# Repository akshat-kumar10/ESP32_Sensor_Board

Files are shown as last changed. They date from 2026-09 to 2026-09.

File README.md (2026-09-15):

# ESP32-C3-02 IoT Sensor Board

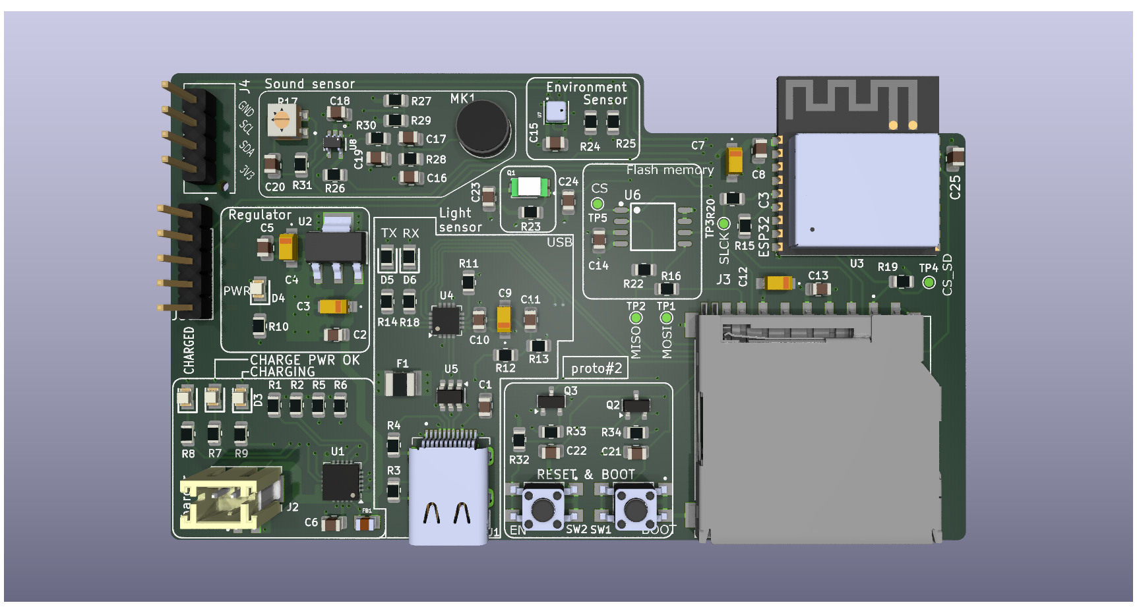
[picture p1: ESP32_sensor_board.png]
PCB Layout


## Overview
This repository contains the KiCad 9.0 design files for a custom IoT sensor board powered by the ESP32-C3-02 SoC[cite: 1]. It features integrated Li-ion battery management and diverse environmental sensors for edge data logging and prototyping[cite: 1].

## Key Features
* **Power Management:** Integrated TP4056 IC for safe single-cell Li-ion charging with thermal regulation, under-voltage lockout, and trickle charging[cite: 1].
* **Dual Power Inputs:** USB-C for charging/data and a dedicated LiPo battery connector[cite: 1].
* **Modular Architecture:** Expandable via additional I2C devices with optimized PCB traces for minimal power loss[cite: 1].

## Primary Components
* **Microcontroller:** ESP32-C3-02 SoC (Wi-Fi and BLE connectivity)[cite: 1].
* **Sensors:** BME280 (temperature, humidity, pressure), ambient light, and sound sensors[cite: 1].
* **Peripherals:** Mini SD card reader, additional flash memory, and I2C OLED display[cite: 1].
* **Charge Indicators:** Dedicated LEDs for charging and full charge status[cite: 1].

## Repository Structure
* `/ESP32 Project Gerbers` - Manufacturing and fabrication files.
* `/Libraries` & `/Project_Library.pretty` - Project-specific symbols and footprints.
* `/Datasheets` - Component documentation[cite: 1].
* `ESP32 sensor board.kicad_pro` - KiCad 9.0 project file.
* `ESP32 sensor board.kicad_pcb` - Physical PCB layout.
* `*.kicad_sch` - Hierarchical schematic design files (Sensors, User Interface, ESP32).

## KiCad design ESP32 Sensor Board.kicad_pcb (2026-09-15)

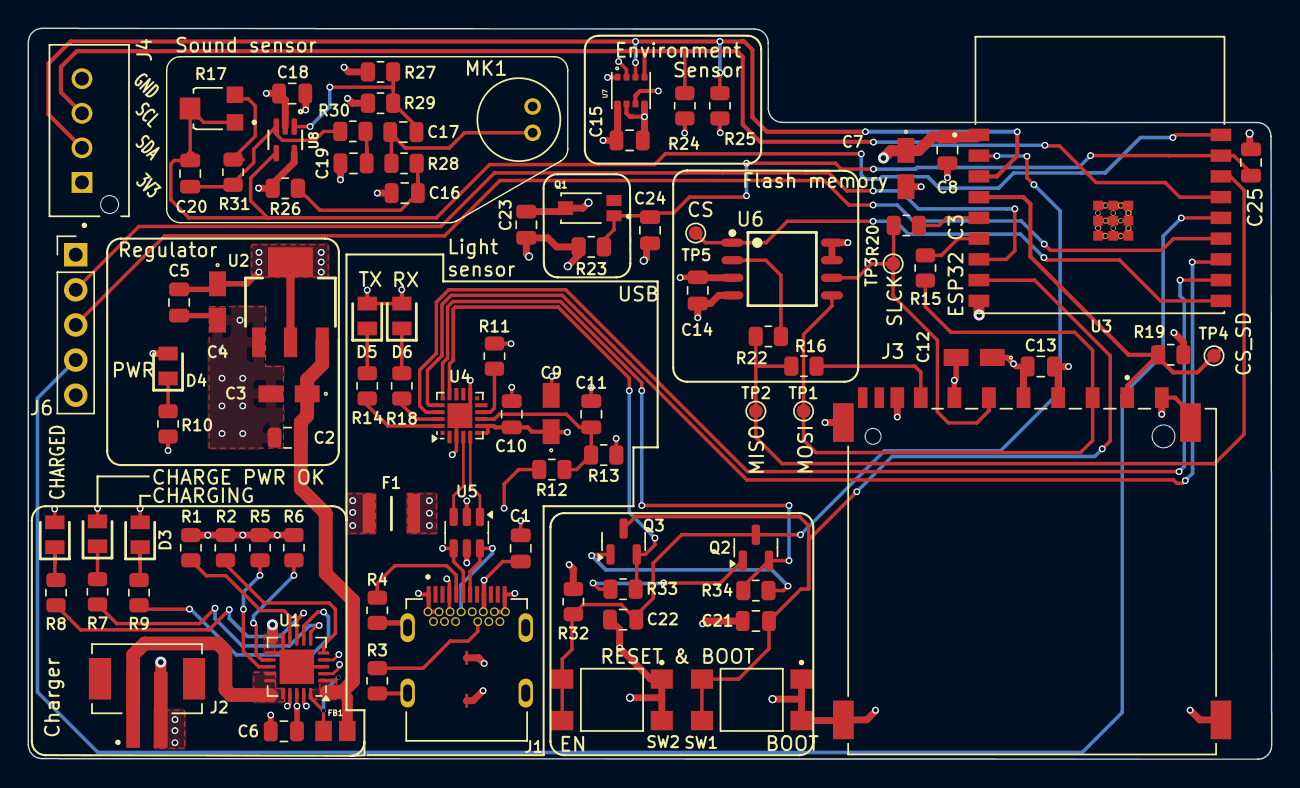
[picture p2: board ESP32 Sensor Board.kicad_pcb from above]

Board: 4 copper layers, 89.9 x 52.8 mm, 90 parts (0 on the bottom side), 60 nets.

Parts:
C1, C2, C5, C8, C10, C13, C14, C15, C16, C18, C21, C23: 0.1u; C_0805_2012Metric
C3, C4, C7, C12: 10u; T491A
C6, C11, C22: 1u; C_0805_2012Metric
C9: 4.7u; T491A
C17, C24, C25: 10n; C_0805_2012Metric
C19: 10u; C_0805_2012Metric
C20: 100p; C_0805_2012Metric
D1, D4, D6: Red; LEDC2012X120N
D2, D5: Green; LEDC2012X120N
D3: Blue; LEDC2012X120N
F1: 0ZCH0110AF2E; FUSC3226X100N
FB1: FBMJ2125HM330-T; BEADC2012X105N
J1: USB_C_Receptacle; BELFUSE_SS-52400-002
J2: JST_2mm_LiPo; JST_B2B-PH-SM4-TB
J3: GSD090012SEU; AMPHENOL_GSD090012SEU
J4: B4B-XH-AM; JST_B4B-XH-AM__LF__SN_
J6: Conn_01x05; PinHeader_1x05_P2.54mm_Vertical
MK1: CMC-5042PF-AC; CUI_CMC-5042PF-AC
Q1: TEMT6000X01; TRANS_TEMT6000X01
Q2, Q3: BC817; SOT-23
R1, R2, R19, R23, R32, R33, R34: 10K; R_0805_2012Metric
R3, R4: 5k1; R_0805_2012Metric
R5, R26, R28: 2K; R_0805_2012Metric
R6: 20K; R_0805_2012Metric
R7, R8, R9: 470; R_0805_2012Metric
R10, R14, R18: 330; R_0805_2012Metric
R11, R30: 1K; R_0805_2012Metric
R12: 22K1; R_0805_2012Metric
R13: 47K5; R_0805_2012Metric
R15, R16, R20, R22: 50; R_0805_2012Metric
R17: 35WR100KLFTR; TRIM_35WR100KLFTR
R24, R25: 4K7; R_0805_2012Metric
R27, R29: 1M; R_0805_2012Metric
R31: 22K; R_0805_2012Metric
SW1, SW2: 1101NE; SW_TL3305AF260QG
TP1: Test MOSI; TestPoint_Pad_D1.0mm
TP2: Test MISO; TestPoint_Pad_D1.0mm
TP3: Test CLK; TestPoint_Pad_D1.0mm
TP4: TEST CS_SD; TestPoint_Pad_D1.0mm
TP5: TEST CS; TestPoint_Pad_D1.0mm
U1: MCP73871; QFN-20-1EP_4x4mm_P0.5mm_EP2.5x2.5mm
U2: LM1117MPX-3.3_NOPB; VREG_LM1117MPX-3.3
U3: ESP32-C3-WROOM-02-H4; MODULE_ESP32-C3-WROOM-02-H4
U4: CP2102N-A02-GQFN20; SiliconLabs_QFN-20-1EP_3x3mm_P0.5mm_EP1.8x1.8mm
U5: USBLC6-2SC6; SOT-23-6
U6: W25Q32JVSSIQ; SOIC127P790X216-8N
U7: BME280; PSON65P250X250X100-8N
U8: MAX4466EXK+T; SOT65P210X110-5N

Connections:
3.3V: C4.1 (+), C5.1, C7.1 (+), C8.1, C9.1 (+), C10.1, C12.1 (+), C13.2, C14.1, C15.2, C18.1, C23.1, D4.2 (A), D5.2 (A), D6.2 (A), J3.4 (VDD1), J4.1, J6.1, Q1.3, R11.1, R19.2, R24.1, R25.1, R26.2, R27.2, R32.2, U2.2 (VOUT_2), U2.4 (VOUT_4), U3.1 (3V3), U4.6 (VDD), U4.7 (VREGIN), U6.3 (~WP(IO2)), U6.7 (~HOLD/~RESET(IO3)), U6.8 (VCC), U7.2 (CSB), U7.6 (VDDIO), U7.8 (VDD), U8.5 (VCC)
+5V: C2.1, C3.1 (+), FB1.1, U2.3 (VIN)
/+5V_USB: C6.1, D1.2 (A), D2.2 (A), D3.2 (A), F1.2, U1.2 (VPCC), U1.4 (PROG2), U1.17 (CE), U1.18 (IN), U1.19 (IN)
/CHARGED: R8.1, U1.8 (STAT1/~LBO)
/CHARGING: R9.1, U1.7 (STAT2)
/CHARGING_POWER_GOOD: R7.1, U1.6 (~PG)
/ESP32-C3-02/BOOT: C21.1, Q3.3 (C), SW1.2, SW1.4, U3.8 (IO9)
/ESP32-C3-02/CS: TP5.1, U3.10 (IO10), U6.1 (~CS)
/ESP32-C3-02/CS_SD: J3.1 (CD/DAT3), R19.1, TP4.1, U3.4 (IO5)
/ESP32-C3-02/DTS: Q3.2 (E), R33.1, U4.15 (~CTS)
/ESP32-C3-02/EN: C22.1, Q2.3 (C), R32.1, SW2.2, SW2.4, U3.2 (EN)
/ESP32-C3-02/GPIO8: J6.2, U3.7 (IO8)
/ESP32-C3-02/GPIO18: J6.3, U3.13 (IO18)
/ESP32-C3-02/GPIO19: J6.4, U3.14 (IO19)
/ESP32-C3-02/MIC_OUT: C20.2, R17.1, R17.2, U3.18 (IO0), U8.4 (OUT)
/ESP32-C3-02/MISO_DO: R16.2, R22.1, TP2.1, U3.16 (IO2)
/ESP32-C3-02/MOSI_DI: J3.2 (CMD), R15.1, TP1.1, U6.5 (DI(IO0))
/ESP32-C3-02/PHOTO_C: C24.1, C25.1, Q1.1, R23.1, U3.17 (IO1)
/ESP32-C3-02/RTS: Q2.2 (E), R34.1, U4.16 (~RTS)
/ESP32-C3-02/RX_TX: U3.12 (TXD), U4.17 (RXD)
/ESP32-C3-02/SCL: J4.3, R24.2, U3.15 (IO3), U7.4 (SCK)
/ESP32-C3-02/SCLK: J3.5 (CLK), R20.1, TP3.1, U6.6 (CLK)
/ESP32-C3-02/SDA: J4.2, R25.2, U3.3 (IO4), U7.3 (SDI)
/ESP32-C3-02/TX_RX: U3.11 (RXD), U4.18 (TXD)
/ESP32-C3-02/USB_D+: U4.4 (D+), U5.3 (I/O2)
/ESP32-C3-02/USB_D-: U4.5 (D-), U5.1 (I/O1)
/PWR_LED: D4.1 (K), R10.2
/USB_DN: J1.A7 (DN1), J1.B7 (DN2), U5.6 (I/O1)
/USB_DP: J1.A6 (DP1), J1.B6 (DP2), U5.4 (I/O2)
/VBAT: J2.1, U1.14 (V_{BAT}), U1.15 (V_{BAT}), U1.16 (V_{BAT_SENSE})
/VBUS: C1.1, F1.1, J1.A4 (VBUSA1), J1.A9 (VBUSA2), J1.B4 (VBUSB1), J1.B9 (VBUSB2), R12.1, U5.5 (VBUS)
GND: C1.2, C2.2, C3.2 (-), C4.2 (-), C5.2, C6.2, C7.2 (-), C8.2, C9.2 (-), C10.2, C11.2, C12.2 (-), C13.1, C14.2, C15.1, C16.2, C18.2, C19.1, C21.2, C22.2, C23.2, C24.2, C25.2, J1.A1 (GNDA1), J1.A12 (GNDA2), J1.B1 (GNDB1), J1.B12 (GNDB2), J1.G1 (GND/SHIELD), J1.G2 (GND/SHIELD), J1.G3 (GND/SHIELD), J1.G4 (GND/SHIELD), J1.S1 (GND/SHIELD), J1.S2 (GND/SHIELD), J1.S3 (GND/SHIELD), J1.S4 (GND/SHIELD), J2.2, J3.3 (VSS1), J3.6 (VSS2), J3.8 (DAT1), J3.9 (DAT2), J3.G1 (SHIELD_GND), J3.G2 (SHIELD_GND), J3.G3 (SHIELD_GND), J3.G4 (SHIELD_GND), J4.4, J6.5, MK1.GND, R1.2, R2.2, R3.2, R4.2, R5.2, R6.2, R10.1, R13.2, R23.2, R29.1, SW1.1, SW1.3, SW2.1, SW2.3, U1.3 (SEL), U1.10 (V_{SS}), U1.11 (V_{SS}), U1.21 (V_{SS}), U2.1 (GND), U3.9 (GND), U3.19 (GND), U3.20 (GND), U3.21 (GND), U3.22 (GND), U3.23 (GND), U3.24 (GND), U3.25 (GND), U3.26 (GND), U3.27 (GND), U3.28 (GND), U3.29 (GND), U3.30 (GND), U3.31 (GND), U3.32 (GND), U3.33 (GND), U3.34 (GND), U3.35 (GND), U3.36 (GND), U3.37 (GND), U3.38 (GND), U3.39 (GND), U4.3 (GND), U4.12 (GND), U4.21 (GND), U5.2 (GND), U6.4 (GND), U7.1 (GND), U7.5 (SDO), U7.7 (GND), U8.2 (GND)
unnamed: C16.1, R26.1, R28.2
unnamed: C17.2, MK1.OUT, R28.1
unnamed: C19.2, R30.1
unnamed: D1.1 (K), R7.2
unnamed: D2.1 (K), R8.2
unnamed: D3.1 (K), R9.2
unnamed: D5.1 (K), R14.2
unnamed: D6.1 (K), R18.2
unnamed: FB1.2, U1.1 (OUT), U1.20 (OUT)
unnamed: J1.A5 (CC1), R4.1
unnamed: J1.B5 (CC2), R3.1
unnamed: J3.7 (DAT0), R16.1
unnamed: Q2.1 (B), R33.2
unnamed: Q3.1 (B), R34.2
unnamed: R17.3, R31.2
unnamed: R5.1, U1.13 (PROG1)
unnamed: R6.1, U1.12 (PROG3)
unnamed: R2.1, U1.5 (THERM)
unnamed: R1.1, U1.9 (~TE)
unnamed: R20.2, U3.5 (IO6)
unnamed: R15.2, U3.6 (IO7)
unnamed: C11.1, R12.2, R13.1, U4.8 (VBUS)
unnamed: R11.2, U4.9 (~RST)
unnamed: R18.1, U4.19 (~RXT/GPIO.3)
unnamed: R14.1, U4.20 (~TXT/GPIO.2)
unnamed: R22.2, U6.2 (DO(IO1))
unnamed: C17.1, R27.1, R29.2, U8.1 (IN+)
unnamed: C20.1, R30.2, R31.1, U8.3 (IN-)

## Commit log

2026-09-15 Add README for ESP32-C3-02 IoT Sensor Board
    Added detailed project information for the ESP32-C3-02 IoT sensor board, including features, components, and repository structure.
2026-09-15 Rename ESP32 sensor board.png to ESP32_sensor_board.png
